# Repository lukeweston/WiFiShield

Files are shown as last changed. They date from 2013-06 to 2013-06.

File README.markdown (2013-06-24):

CC3000 Arduino-compatible 802.11b/g Wi-Fi shield   

Board must be fabbed with 1.6mm thick FR4 (although the microstrip impedence is not a strong function of board thickness), 2-layer 1 oz. Cu, with soldermask on both sides,
so that the 50-ohm coplanar waveguide has an impedence in the right ballpark.   
   
Preview image:   
  
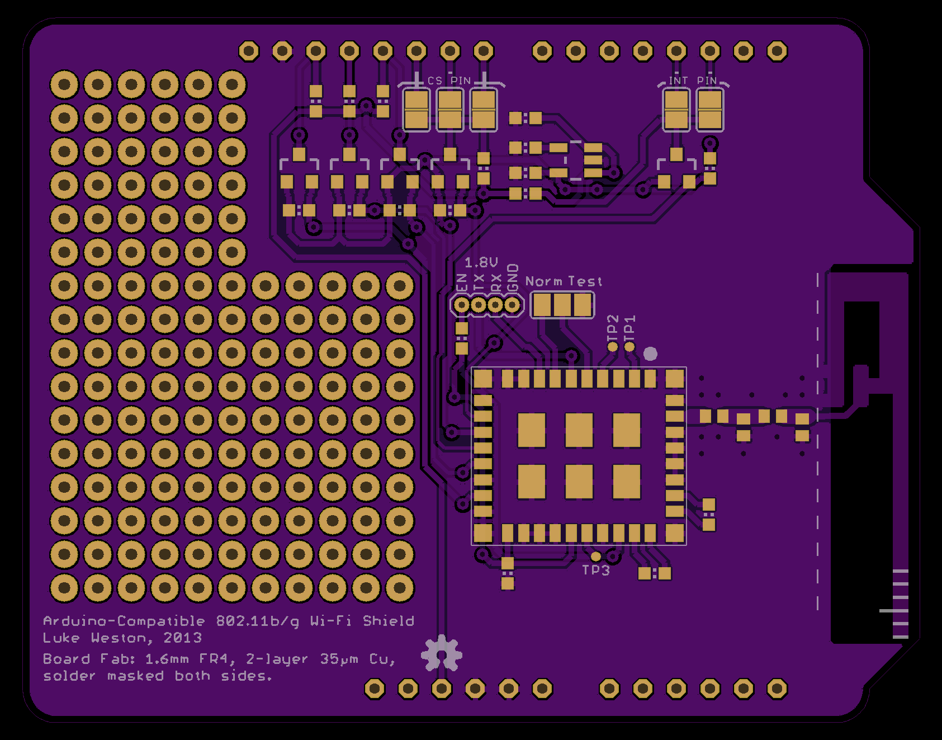
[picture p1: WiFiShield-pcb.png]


Readme to be done later.

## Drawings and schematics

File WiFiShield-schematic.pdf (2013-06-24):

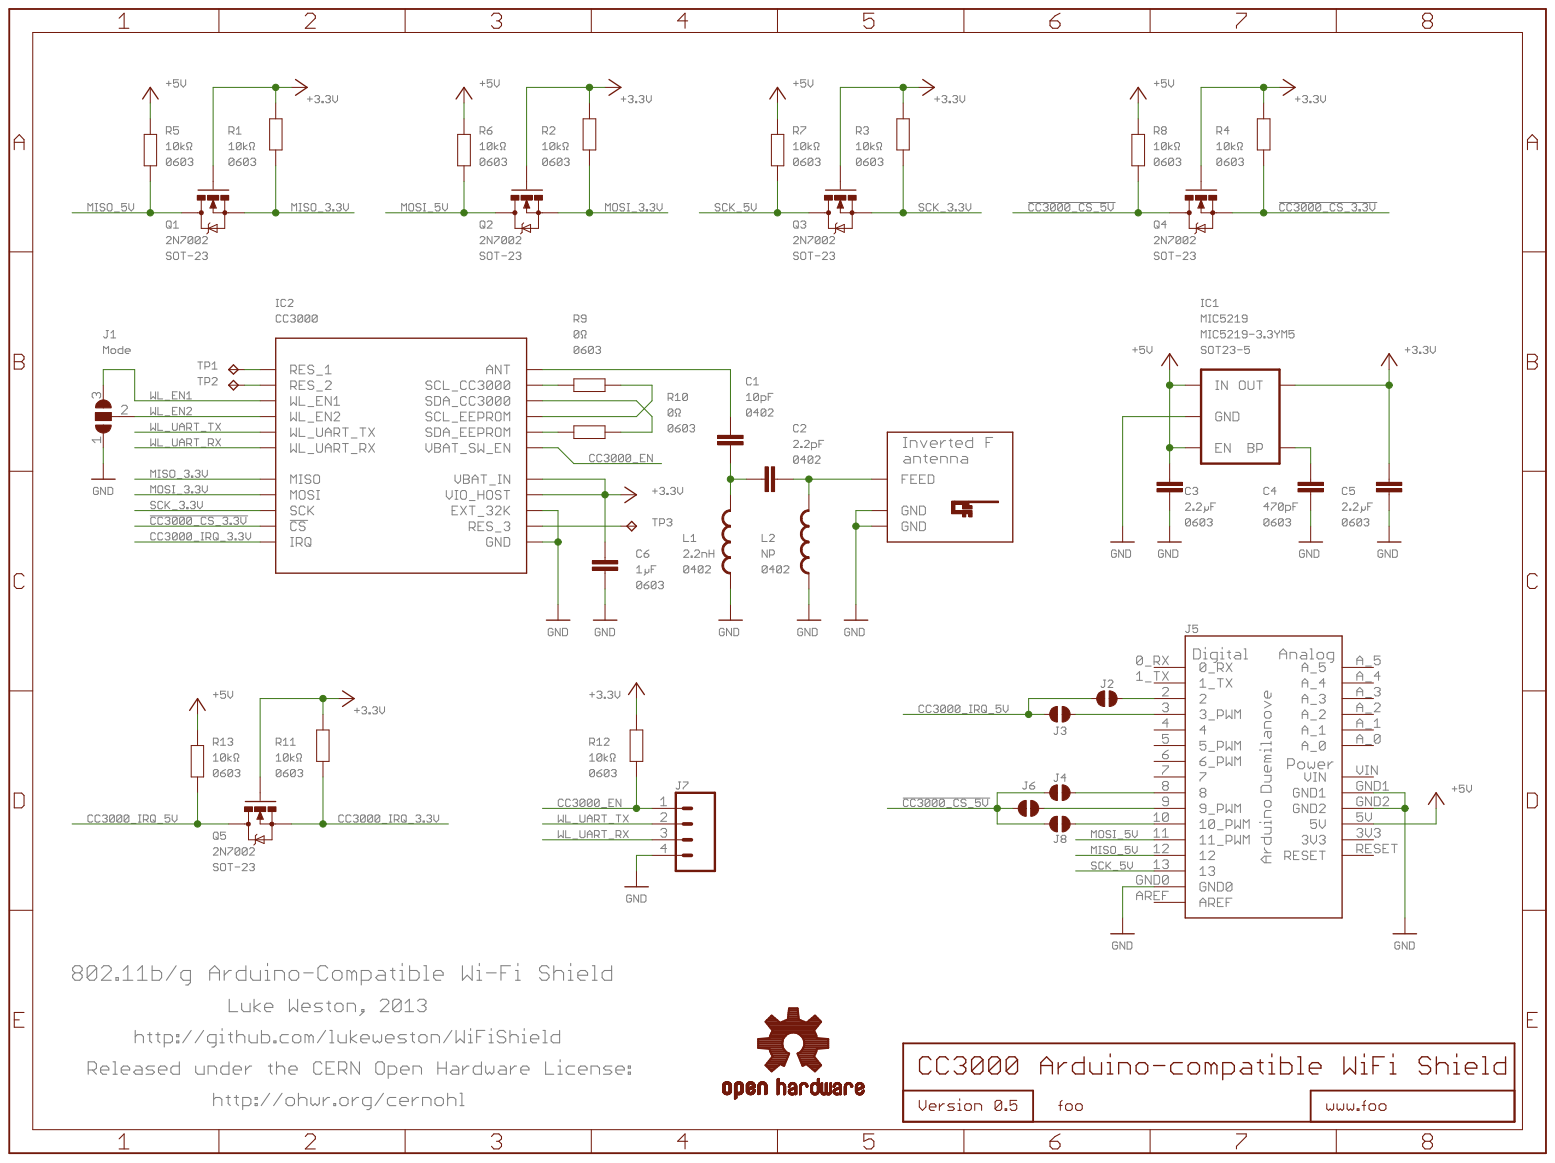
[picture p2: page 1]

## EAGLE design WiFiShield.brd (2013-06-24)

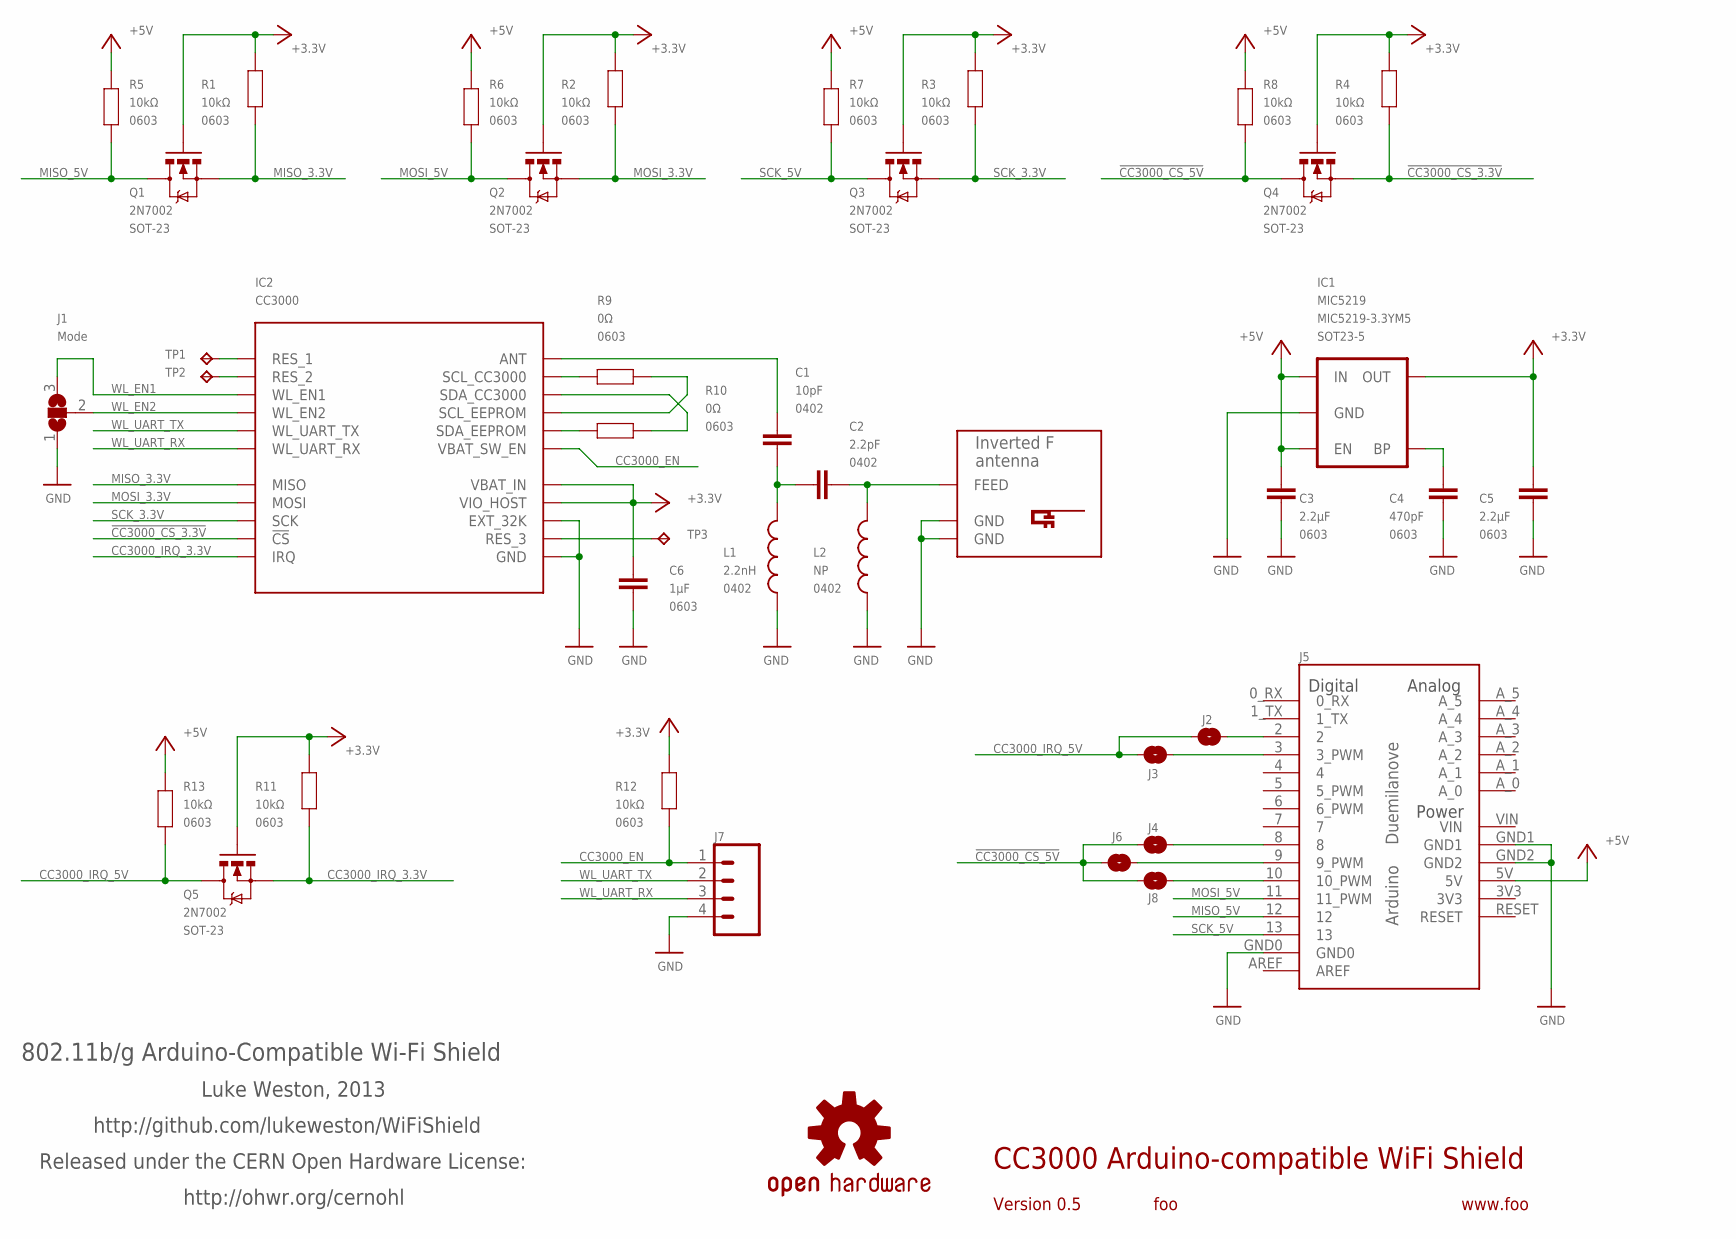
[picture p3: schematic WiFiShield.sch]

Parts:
A1: INVERTED_F_ANTENNA+2; DN007+2
C1: 10pF; C0402
C2: 2.2pF; C0402
C3, C5: 2.2µF; 0603
C4: 470pF; 0603
C6: 1µF; 0603
IC1: MIC5219; SOT23-5
IC2: CC3000
J1: Mode; SJ_2
J2, J3, J4, J6, J8: SJ
J5: Arduino-compatible headers; NO-OUTLINE-OCTAGONAL-NOTEXT
J7: M041.27MM; 1X04-1.27MM
L1: 2.2nH; C0402
L2: NP; C0402
Q1, Q2, Q3, Q4, Q5: 2N7002; SOT23-3
R1, R2, R3, R4, R5, R6, R7, R8, R11, R12, R13: 10kΩ; 0603
R9, R10: 0Ω; 0603
SY: OSHW-LOGOS; OSHW-LOGO-S
TP1, TP2, TP3: TPTP06R; TP06R

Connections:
3V3: J5.3V3
!CC3000_CS_3.3V: IC2.12 (!CS), Q4.2 (S), R4.1
!CC3000_CS_5V: J4.1, J6.1, J8.1, Q4.3 (D), R8.1
+3V3: C5.1, C6.2, IC1.5 (OUT), IC2.19 (VBAT_IN), IC2.23 (VIO_HOST), Q1.1 (G), Q2.1 (G), Q3.1 (G), Q4.1 (G), Q5.1 (G), R1.2, R2.2, R3.2, R4.2, R11.2, R12.2
+5V: C3.2, IC1.1 (IN), IC1.3 (EN), J5.5V, R5.2, R6.2, R7.2, R8.2, R13.2
CC3000_EN: IC2.26 (VBAT_SW_EN), J7.1, R12.1
CC3000_IRQ_3.3V: IC2.14 (IRQ), Q5.2 (S), R11.1
CC3000_IRQ_5V: J2.1, J3.1, Q5.3 (D), R13.1
GND: A1.GND, A1.GND@1 (GND), C3.1, C4.1, C5.2, C6.1, IC1.2 (GND), IC2.1 (GND), IC2.9 (GND), IC2.10 (GND), IC2.11 (GND), IC2.16 (GND), IC2.18 (GND), IC2.20 (GND), IC2.21 (EXT_32K), IC2.22 (GND), IC2.25 (GND), IC2.31 (GND), IC2.32 (GND), IC2.33 (GND), IC2.34 (GND), IC2.36 (GND), IC2.37 (GND), IC2.38 (GND), IC2.39 (GND), IC2.40 (GND), IC2.41 (GND), IC2.42 (GND), IC2.43 (GND), IC2.44 (GND), IC2.45 (GND), IC2.46 (GND), J1.1, J5.GND0, J5.GND1, J5.GND2, J7.4, L1.2, L2.2
MISO_3.3V: IC2.13 (MISO), Q1.2 (S), R1.1
MISO_5V: J5.12, Q1.3 (D), R5.1
MOSI_3.3V: IC2.15 (MOSI), Q2.2 (S), R2.1
MOSI_5V: J5.11 (11_PWM), Q2.3 (D), R6.1
unnamed: IC2.27 (SDA_EEPROM), R10.2
unnamed: IC2.28 (SDA_CC3000), R10.1
unnamed: J3.2, J5.3 (3_PWM)
unnamed: IC2.29 (SCL_EEPROM), R9.1
unnamed: J2.2, J5.2
unnamed: J5.9 (9_PWM), J6.2
unnamed: J4.2, J5.8
unnamed: J5.10 (10_PWM), J8.2
unnamed: IC2.30 (SCL_CC3000), R9.2
unnamed: C1.2, IC2.35 (ANT)
unnamed: C4.2, IC1.4 (BP)
unnamed: C1.1, C2.2, L1.1
unnamed: A1.FEED, C2.1, L2.1
RES_1: IC2.2 (RES_1), TP1.TP
RES_2: IC2.4 (RES_2), TP2.TP
RES_3: IC2.24 (RES_3), TP3.TP
SCK_3.3V: IC2.17 (SCK), Q3.2 (S), R3.1
SCK_5V: J5.13, Q3.3 (D), R7.1
VIN: J5.VIN
WL_EN1: IC2.7 (WL_EN1), J1.3
WL_EN2: IC2.5 (WL_EN2), J1.2
WL_UART_RX: IC2.8 (WL_UART_RX), J7.3
WL_UART_TX: IC2.6 (WL_UART_TX), J7.2

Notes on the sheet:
CC3000 Arduino-compatible WiFi Shield
Version 0.5
foo
www.foo
802.11b/g Arduino-Compatible Wi-Fi Shield
Luke Weston, 2013
http://github.com/lukeweston/WiFiShield
Released under the CERN Open Hardware License:
http://ohwr.org/cernohl

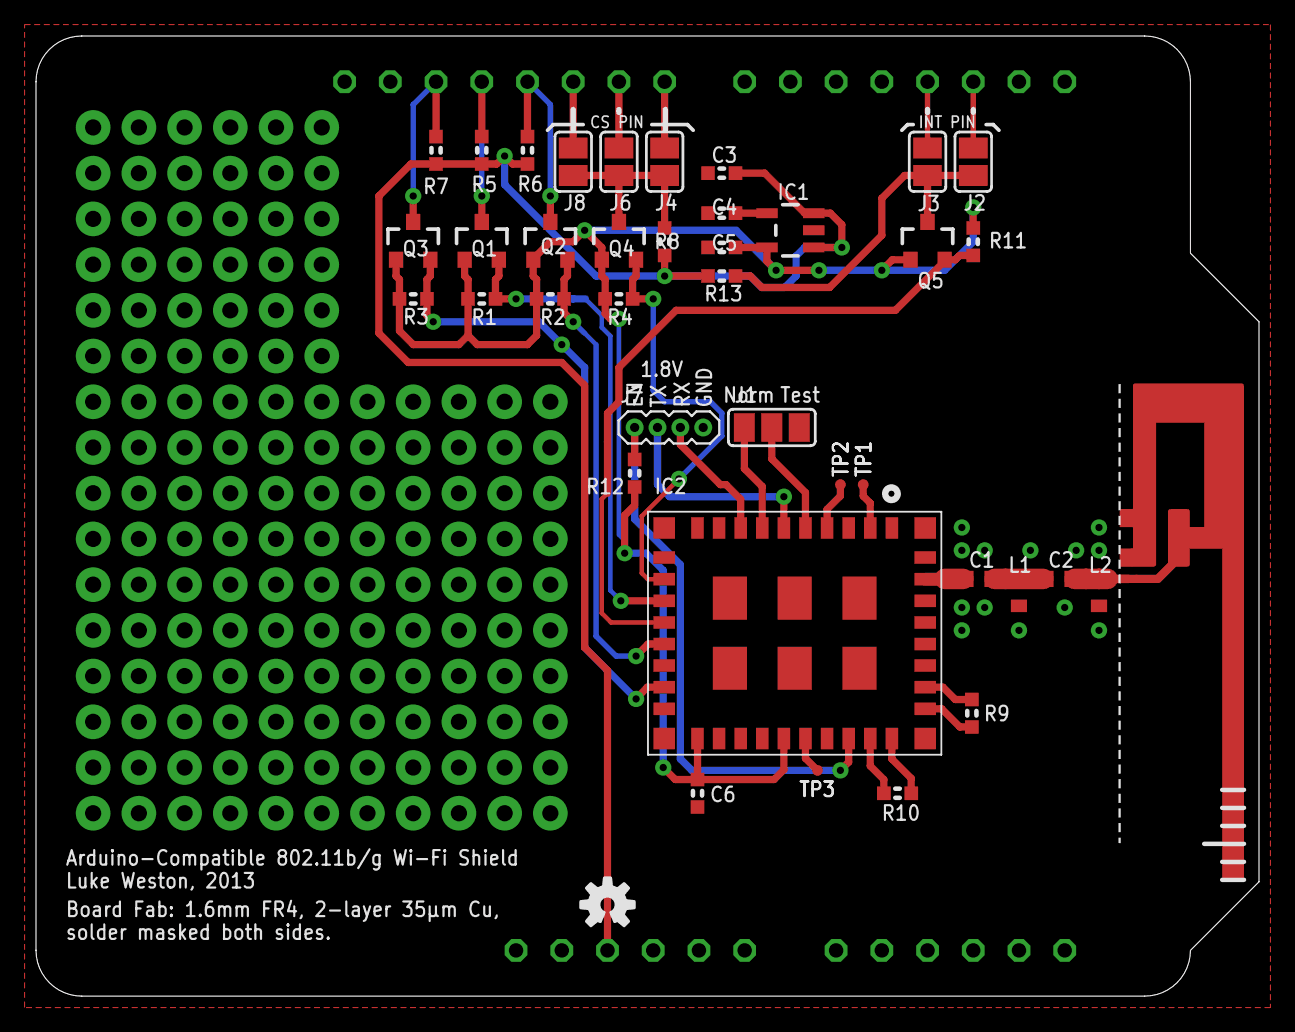
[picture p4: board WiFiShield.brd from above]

Board: 2 copper layers, 67.9 x 53.3 mm, 41 parts (0 on the bottom side), 34 nets.

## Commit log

2013-03-17 tweaked schematic
2013-03-17 tweaked readme
    [WiFiShield.brd]
2013-03-17 finished silkscreen
    [WiFiShield.brd, WiFiShield.sch]
2013-04-06 added gerbers
    [WiFiShield.GBL, WiFiShield.GBS, WiFiShield.GTL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]
2013-04-08 tweaked RF layout
    [WiFiShield.brd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]
2013-06-24 changed to microstrip antenna, fixed 50Ω line
    [WiFiShield.brd, WiFiShield.sch]
2013-06-24 fixed coplanar waveguide, regenerated board image
